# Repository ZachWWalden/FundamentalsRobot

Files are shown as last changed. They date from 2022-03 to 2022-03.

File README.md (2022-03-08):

# FundamentalsRobot
Reference Design Robot PCB for Oklahoma Christian University's Introductory E.C.E. Course, Fundamentals.
This design is meant to guide you in designing the schematic and possibly give some general layout tips.

# Things To Note
This design is not intended to be manufactured. This was achieved using surface mount resistors, capacitors, and screw terminals that the school does not have.
Over the few lessons we will do, we will build a board that uses components the school does have and, that if you so wish could be manufactured.

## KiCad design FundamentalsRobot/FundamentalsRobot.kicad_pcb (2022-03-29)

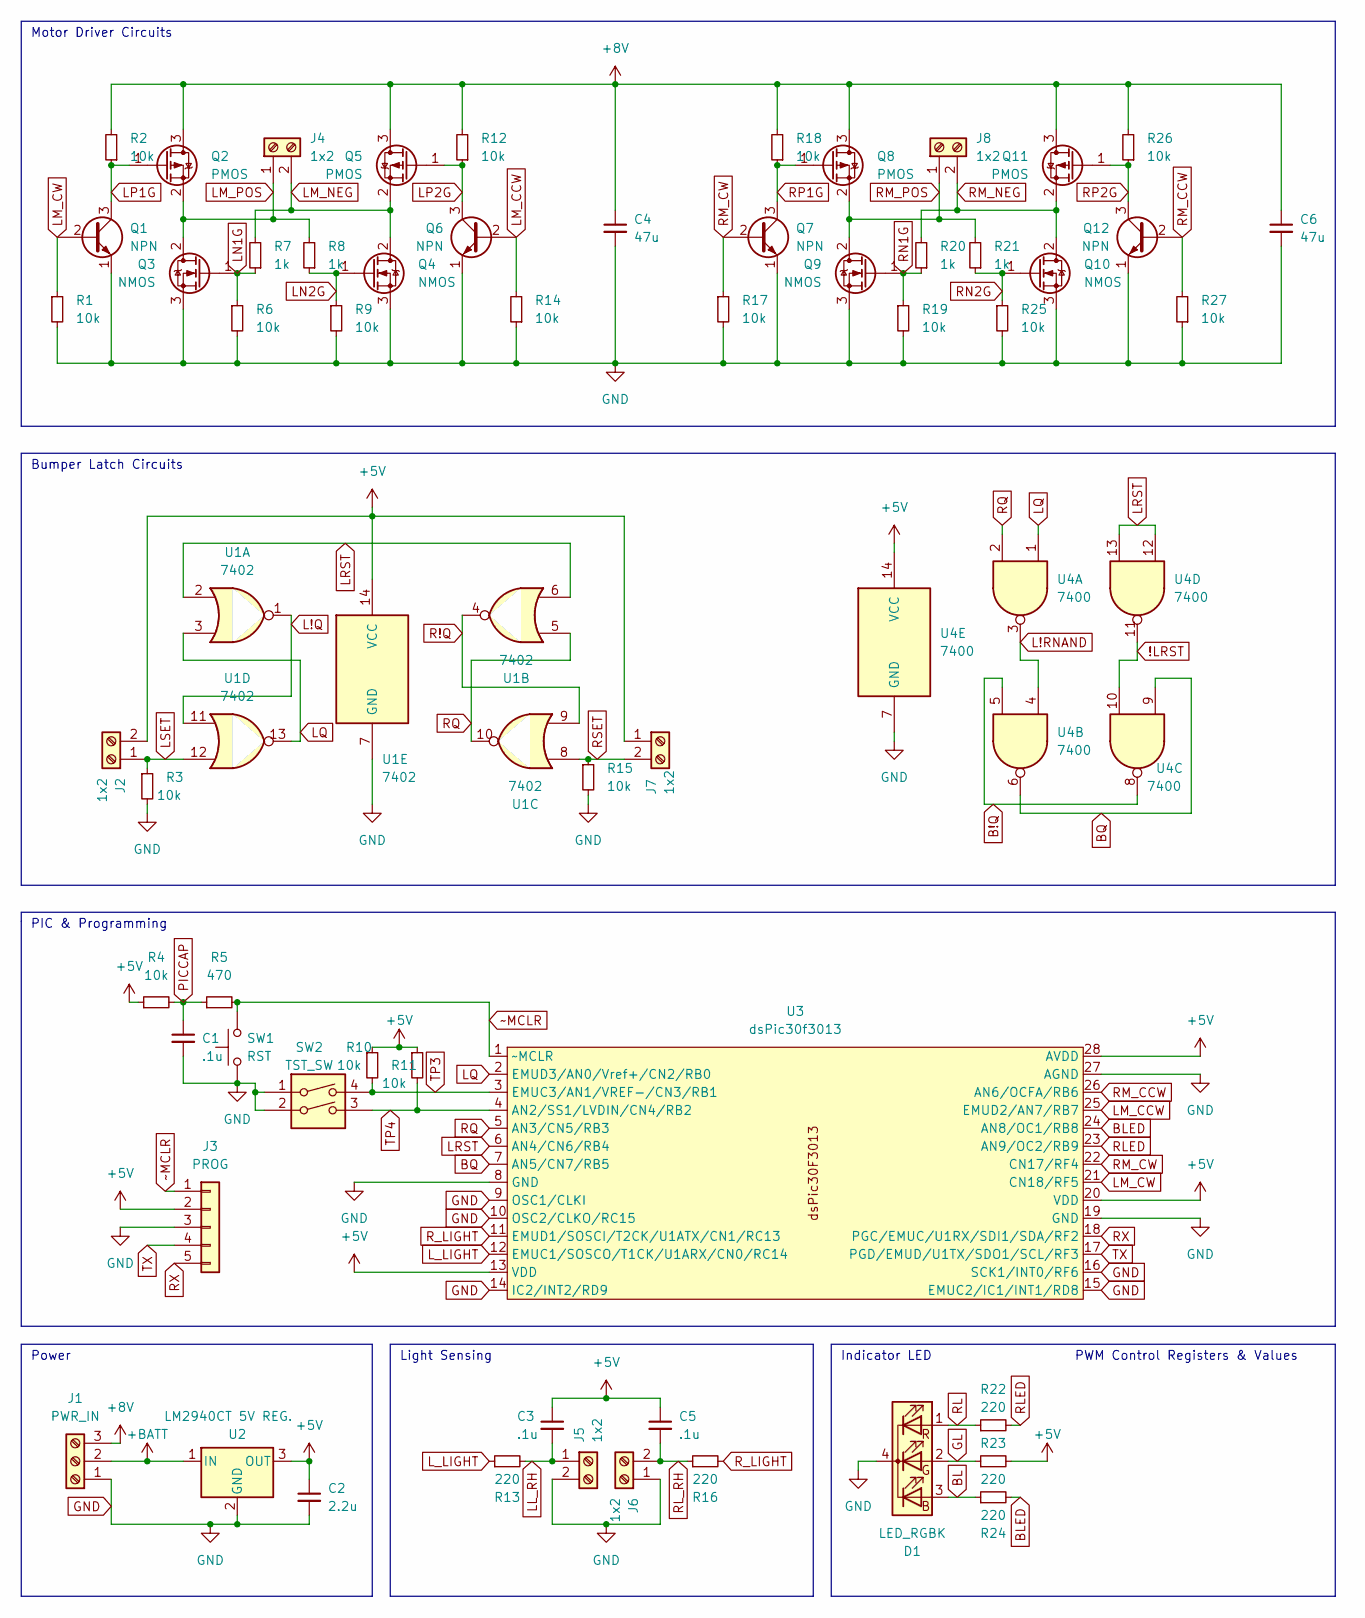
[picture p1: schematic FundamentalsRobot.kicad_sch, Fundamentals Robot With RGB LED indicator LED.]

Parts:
C1, C3, C5: .1u; C_0603_1608Metric
C2: 2.2u; C_0603_1608Metric
C4, C6: 47u; C_1206_3216Metric
D1: LED_RGBK; RKGB
J1: PWR_IN; TerminalBlock_Altech_AK300-3_P5.00mm
J2, J4, J5, J6, J7, J8: 1x2; TerminalBlock_Altech_AK300-2_P5.00mm
J3: PROG; PinHeader_1x05_P2.54mm_Vertical
Q1, Q6, Q7, Q12: NPN; TO-92
Q2, Q5, Q8, Q11: PMOS; TO-220-3_Vertical
Q3, Q4, Q9, Q10: NMOS; TO-220-3_Vertical
R1, R2, R3, R4, R6, R9, R10, R11, R12, R14, R15, R17, R18, R19, R25, R26, R27: 10k; R_0603_1608Metric
R5: 470; R_0603_1608Metric
R7, R8, R20, R21: 1k; R_0603_1608Metric
R13, R16, R22, R23, R24: 220; R_0603_1608Metric
SW1: RST; PinHeader_1x02_P2.54mm_Vertical
SW2: TST_SW; SW_DIP_SPSTx02_Piano_CTS_Series194-2MSTN_W7.62mm_P2.54mm
U1: 7402; DIP-14_W7.62mm
U2: LM2940CT 5V REG.; TO-220-3_Vertical
U3: dsPic30f3013; DIP-28_W7.62mm
U4: 7400; DIP-14_W7.62mm

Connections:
!LRST: U4.10, U4.11
+5V: C2.1, C3.1, C5.1, J2.2, J3.2, J7.1, R4.1, R10.1, R11.1, R23.2, U1.14 (VCC), U2.3 (OUT), U3.13 (VDD), U3.20 (VDD), U3.28 (AVDD), U4.14 (VCC)
+8V: C4.1, C6.1, J1.3, Q2.3 (D), Q5.3 (D), Q8.3 (D), Q11.3 (D), R2.2, R12.2, R18.2, R26.2
+BATT: J1.2, U2.1 (IN)
B!Q: U4.5, U4.8
BL: D1.3 (BA), R24.1
BLED: R24.2, U3.24 (AN8/OC1/RB8)
BQ: U3.7 (AN5/CN7/RB5), U4.6, U4.9
GL: D1.2 (GA), R23.1
GND: C1.2, C2.2, C4.2, C6.2, D1.4 (K), J1.1, J3.3, J5.2, J6.1, Q1.1 (E), Q3.3 (S), Q4.3 (S), Q6.1 (E), Q7.1 (E), Q9.3 (S), Q10.3 (S), Q12.1 (E), R1.2, R3.2, R6.2, R9.2, R14.1, R15.2, R17.2, R19.2, R25.2, R27.1, SW1.1, SW2.1, SW2.2, U1.7 (GND), U2.2 (GND), U3.8 (GND), U3.9 (OSC1/CLKI), U3.10 (OSC2/CLKO/RC15), U3.14 (IC2/INT2/RD9), U3.15 (EMUC2/IC1/INT1/RD8), U3.16 (SCK1/INT0/RF6), U3.19 (GND), U3.27 (AGND), U4.7 (GND)
L!Q: U1.1, U1.11
L!RNAND: U4.3, U4.4
LL_RH: C3.2, J5.1, R13.2
LM_CCW: Q6.2 (B), R14.2, U3.25 (EMUD2/AN7/RB7)
LM_CW: Q1.2 (B), R1.1, U3.21 (CN18/RF5)
LM_NEG: J4.2, Q4.2 (D), Q5.2 (S), R7.2
LM_POS: J4.1, Q2.2 (S), Q3.2 (D), R8.2
LN1G: Q3.1 (G), R6.1, R7.1
LN2G: Q4.1 (G), R8.1, R9.1
LP1G: Q1.3 (C), Q2.1 (G), R2.1
LP2G: Q5.1 (G), Q6.3 (C), R12.1
LQ: U1.3, U1.13, U3.2 (EMUD3/AN0/Vref+/CN2/RB0), U4.1
LRST: U1.2, U1.6, U3.6 (AN4/CN6/RB4), U4.12, U4.13
LSET: J2.1, R3.1, U1.12
L_LIGHT: R13.1, U3.12 (EMUC1/SOSCO/T1CK/U1ARX/CN0/RC14)
PICCAP: C1.1, R4.2, R5.1
R!Q: U1.4, U1.9
RL: D1.1 (RA), R22.1
RLED: R22.2, U3.23 (AN9/OC2/RB9)
RL_RH: C5.2, J6.2, R16.1
RM_CCW: Q12.2 (B), R27.2, U3.26 (AN6/OCFA/RB6)
RM_CW: Q7.2 (B), R17.1, U3.22 (CN17/RF4)
RM_NEG: J8.2, Q10.2 (D), Q11.2 (S), R20.2
RM_POS: J8.1, Q8.2 (S), Q9.2 (D), R21.2
RN1G: Q9.1 (G), R19.1, R20.1
RN2G: Q10.1 (G), R21.1, R25.1
RP1G: Q7.3 (C), Q8.1 (G), R18.1
RP2G: Q11.1 (G), Q12.3 (C), R26.1
RQ: U1.5, U1.10, U3.5 (AN3/CN5/RB3), U4.2
RSET: J7.2, R15.1, U1.8
RX: J3.5, U3.18 (PGC/EMUC/U1RX/SDI1/SDA/RF2)
R_LIGHT: R16.2, U3.11 (EMUD1/SOSCI/T2CK/U1ATX/CN1/RC13)
TP3: R10.2, SW2.4, U3.3 (EMUC3/AN1/VREF-/CN3/RB1)
TP4: R11.2, SW2.3, U3.4 (AN2/SS1/LVDIN/CN4/RB2)
TX: J3.4, U3.17 (PGD/EMUD/U1TX/SDO1/SCL/RF3)
~MCLR: J3.1, R5.2, SW1.2, U3.1 (~MCLR)

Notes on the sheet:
Indicator LED
Power
Motor Driver Circuits
Light Sensing
PIC & Programming
Bumper Latch Circuits
PWM Control Registers & Values

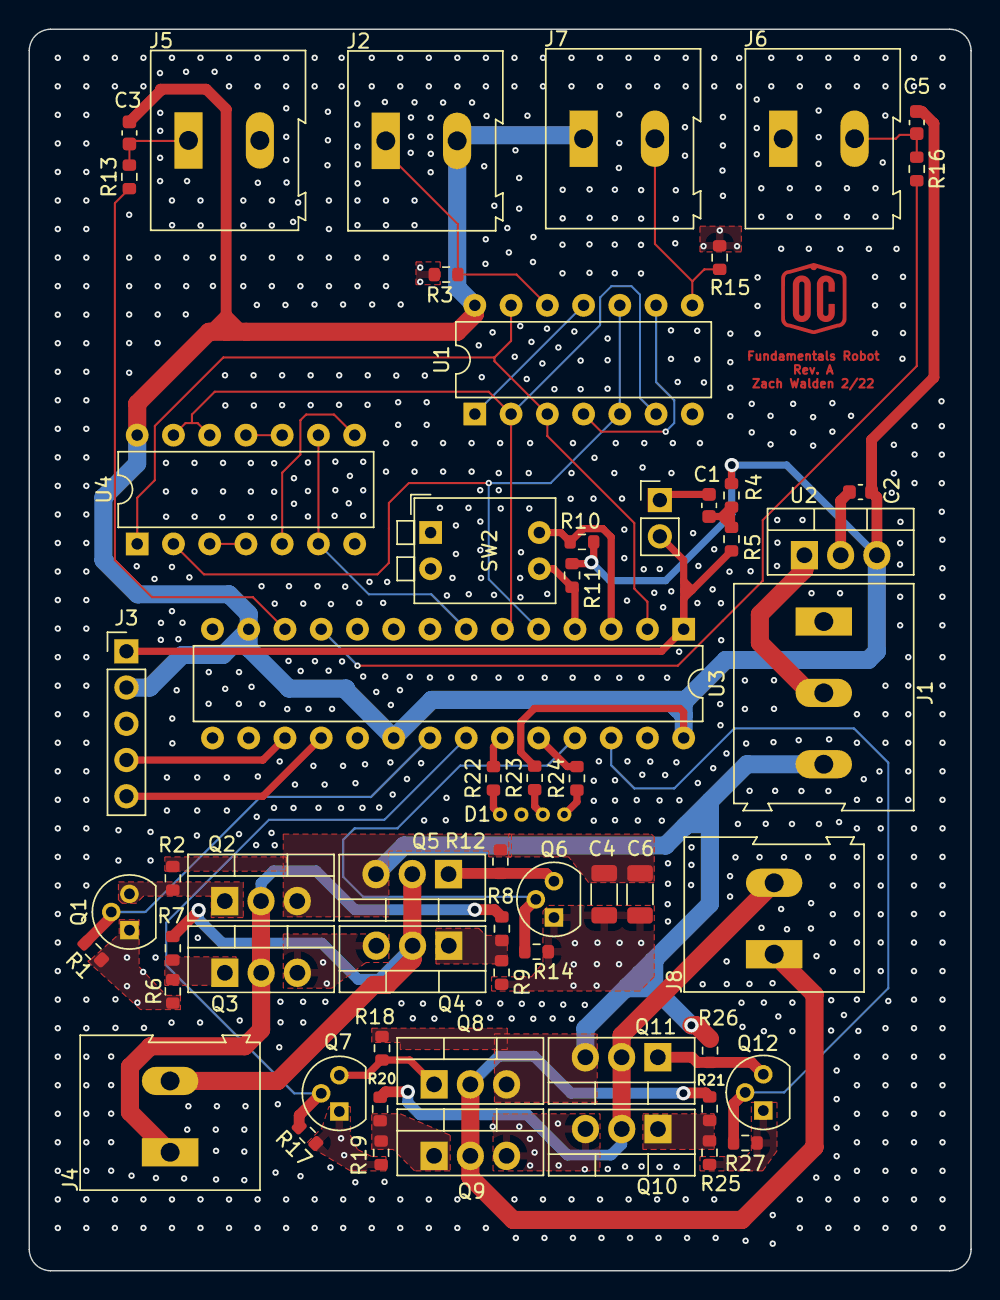
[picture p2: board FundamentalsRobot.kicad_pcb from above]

Board: 4 copper layers, 66.0 x 87.0 mm, 60 parts (0 on the bottom side), 46 nets.

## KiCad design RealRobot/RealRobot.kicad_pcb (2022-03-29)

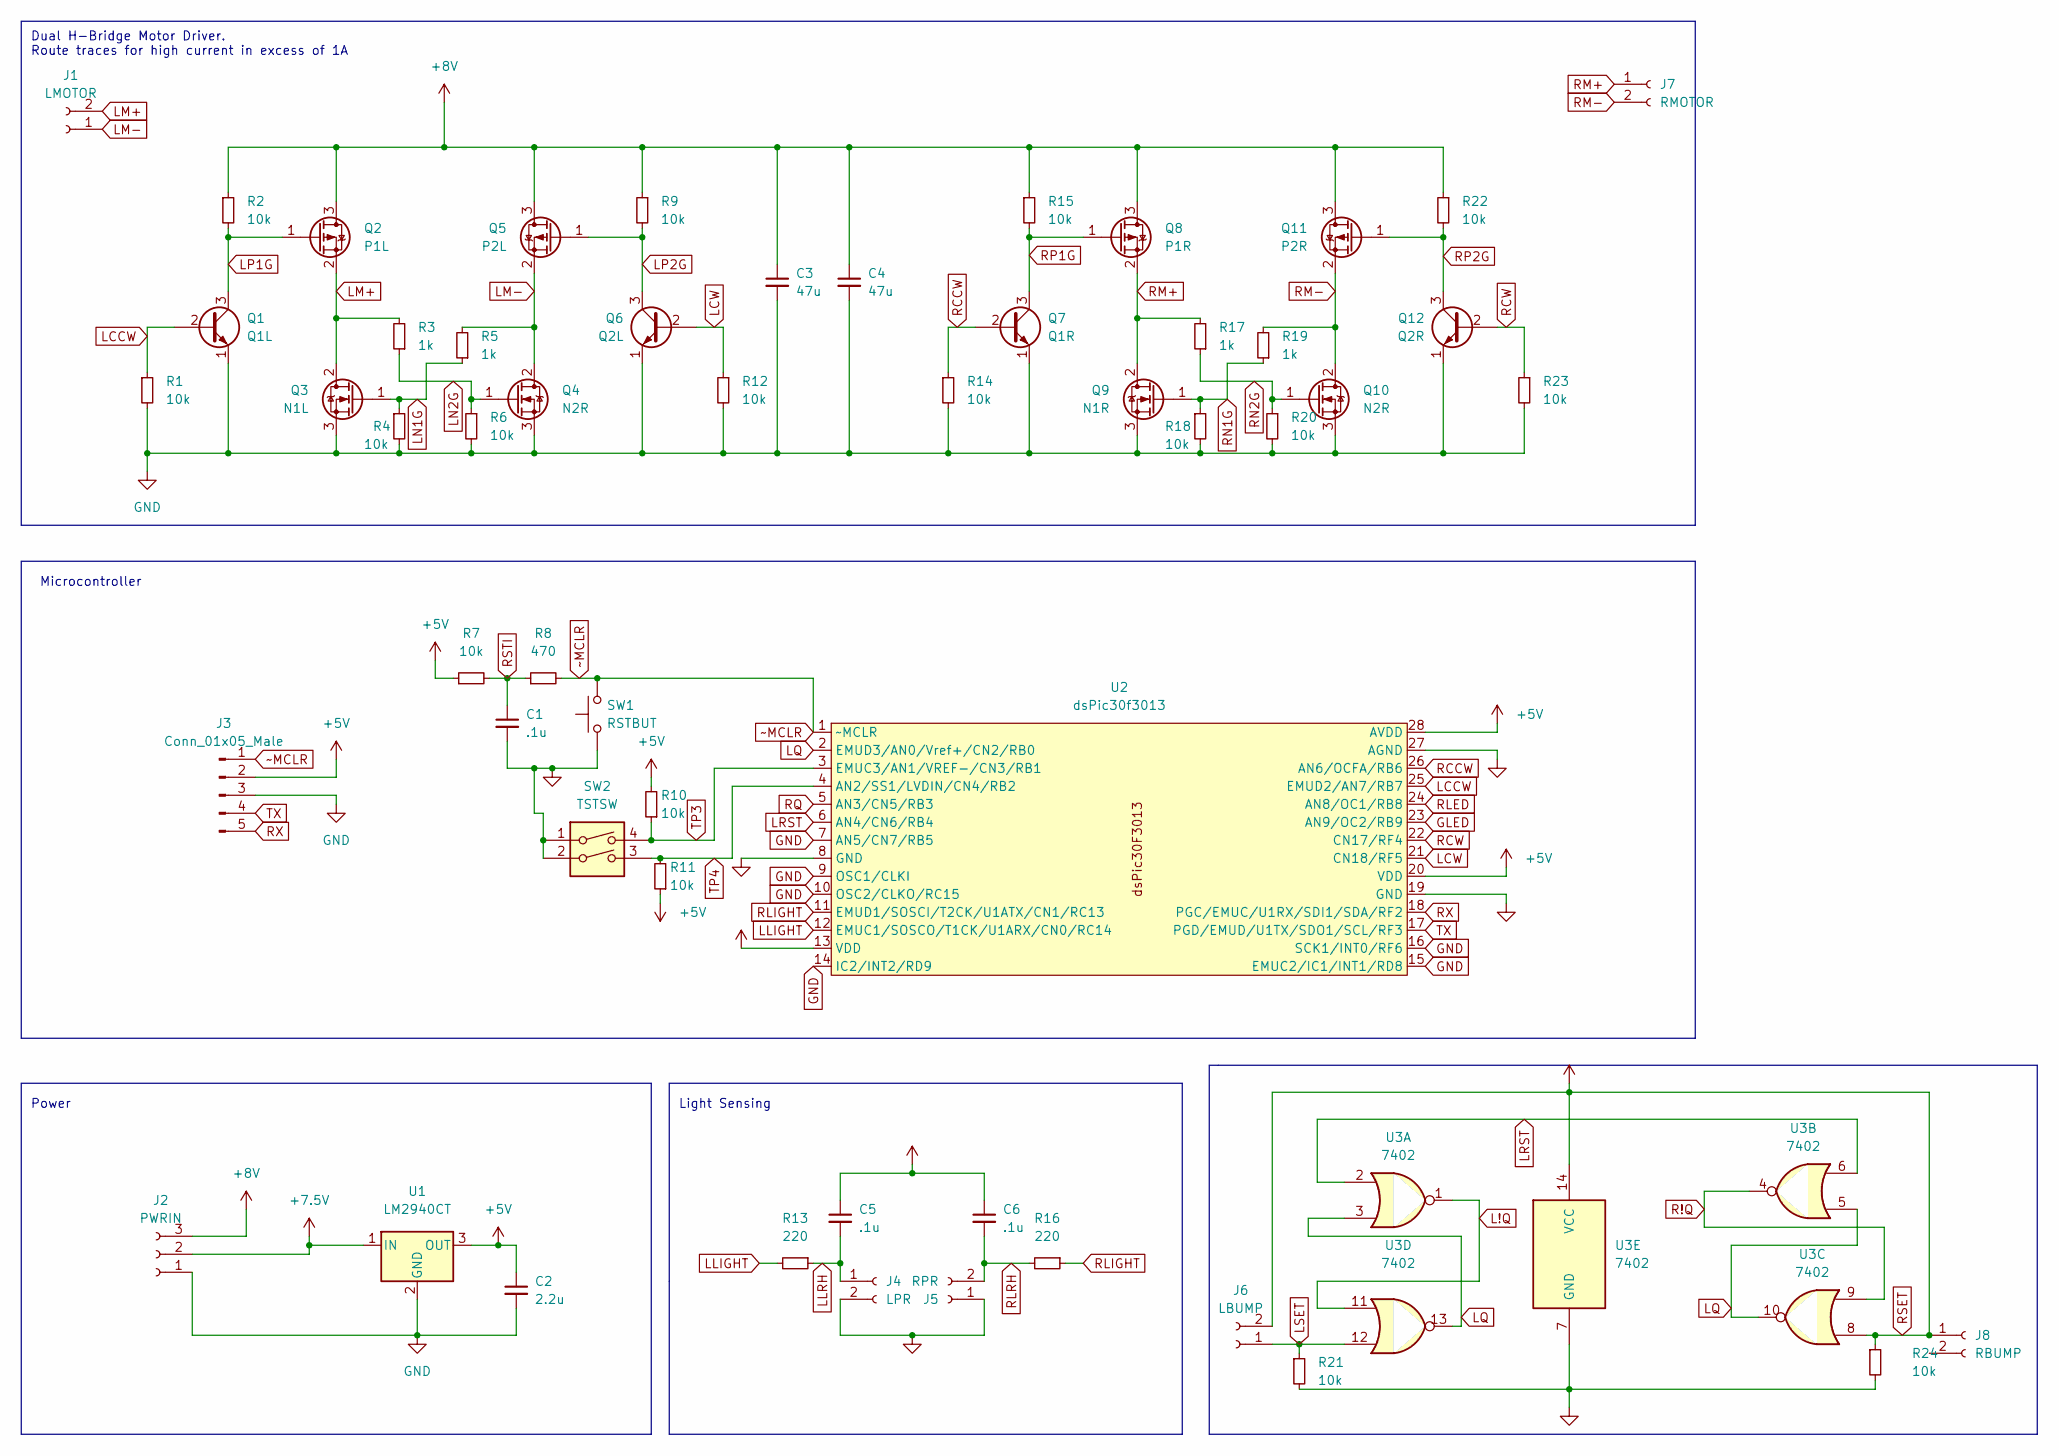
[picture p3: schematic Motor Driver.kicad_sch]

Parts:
C1, C5, C6: .1u; CP_Radial_D4.0mm_P1.50mm
C2: 2.2u; CP_Radial_D5.0mm_P2.00mm
C3, C4: 47u; CP_Radial_D5.0mm_P2.50mm
J1: LMOTOR
J2: PWRIN; PinHeader_1x03_P2.54mm_Vertical
J3: Conn_01x05_Male; PinHeader_1x05_P2.54mm_Vertical
J4: LPR; PinHeader_1x02_P2.54mm_Vertical
J5: RPR; PinHeader_1x02_P2.54mm_Vertical
J6: LBUMP; PinHeader_1x02_P2.54mm_Vertical
J7: RMOTOR; PinHeader_1x02_P2.54mm_Vertical
J8: RBUMP; PinHeader_1x02_P2.54mm_Vertical
Q1: Q1L; TO-92
Q2: P1L; TO-220-3_Vertical
Q3: N1L; TO-220-3_Vertical
Q4, Q10: N2R; TO-220-3_Vertical
Q5: P2L; TO-220-3_Vertical
Q6: Q2L; TO-92
Q7: Q1R; TO-92
Q8: P1R; TO-220-3_Vertical
Q9: N1R; TO-220-3_Vertical
Q11: P2R; TO-220-3_Vertical
Q12: Q2R; TO-92
R1, R2, R4, R6, R7, R9, R10, R11, R12, R14, R15, R18, R20, R21, R22, R23, R24: 10k; R_Axial_DIN0207_L6.3mm_D2.5mm_P10.16mm_Horizontal
R3, R5, R17, R19: 1k; R_Axial_DIN0207_L6.3mm_D2.5mm_P10.16mm_Horizontal
R8: 470; R_Axial_DIN0207_L6.3mm_D2.5mm_P10.16mm_Horizontal
R13, R16: 220; R_Axial_DIN0207_L6.3mm_D2.5mm_P10.16mm_Horizontal
SW1: RSTBUT; PinHeader_1x02_P2.54mm_Vertical
SW2: TSTSW; SW_DIP_SPSTx02_Piano_CTS_Series194-2MSTN_W7.62mm_P2.54mm
U1: LM2940CT; TO-220-3_Vertical
U2: dsPic30f3013; DIP-28_W7.62mm
U3: 7402; DIP-14_W7.62mm

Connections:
+7.5V: J2.2, U1.1 (IN)
+8V: C3.1, C4.1, J2.3, Q2.3 (D), Q5.3 (D), Q8.3 (D), Q11.3 (D), R2.1, R9.1, R15.1, R22.1
GLED: U2.23 (AN9/OC2/RB9)
L!Q: U3.1, U3.11
LCCW: Q1.2 (B), R1.1, U2.25 (EMUD2/AN7/RB7)
LCW: Q6.2 (B), R12.1, U2.21 (CN18/RF5)
LLIGHT: R13.2, U2.12 (EMUC1/SOSCO/T1CK/U1ARX/CN0/RC14)
LLRH: C5.2, J4.1, R13.1
LM+: J1.2, Q2.2 (S), Q3.2 (D), R3.2
LM-: J1.1, Q4.2 (D), Q5.2 (S), R5.2
LN1G: Q3.1 (G), R4.1, R5.1
LN2G: Q4.1 (G), R3.1, R6.1
LP1G: Q1.3 (C), Q2.1 (G), R2.2
LP2G: Q5.1 (G), Q6.3 (C), R9.2
LQ: U2.2 (EMUD3/AN0/Vref+/CN2/RB0), U3.3, U3.5, U3.10, U3.13
LRST: U2.6 (AN4/CN6/RB4), U3.2, U3.6
LSET: J6.1, R21.1, U3.12
R!Q: U3.4, U3.9
RCCW: Q7.2 (B), R14.1, U2.26 (AN6/OCFA/RB6)
RCW: Q12.2 (B), R23.1, U2.22 (CN17/RF4)
RLED: U2.24 (AN8/OC1/RB8)
RLIGHT: R16.1, U2.11 (EMUD1/SOSCI/T2CK/U1ATX/CN1/RC13)
RLRH: C6.2, J5.2, R16.2
RM+: J7.1, Q8.2 (S), Q9.2 (D), R17.2
RM-: J7.2, Q10.2 (D), Q11.2 (S), R19.2
RN1G: Q9.1 (G), R18.1, R19.1
RN2G: Q10.1 (G), R17.1, R20.1
RP1G: Q7.3 (C), Q8.1 (G), R15.2
RP2G: Q11.1 (G), Q12.3 (C), R22.2
RQ: U2.5 (AN3/CN5/RB3)
RSTI: C1.1, R7.2, R8.1
RX: J3.5, U2.18 (PGC/EMUC/U1RX/SDI1/SDA/RF2)
TP3: R10.1, SW2.4, U2.3 (EMUC3/AN1/VREF-/CN3/RB1)
TP4: R11.2, SW2.3, U2.4 (AN2/SS1/LVDIN/CN4/RB2)
TX: J3.4, U2.17 (PGD/EMUD/U1TX/SDO1/SCL/RF3)
~MCLR: J3.1, R8.2, SW1.2, U2.1 (~MCLR)

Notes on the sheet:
Microcontroller
Light Sensing
Dual H-Bridge Motor Driver. Route traces for high current in excess of 1A
Power

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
Board: 2 copper layers, 55 parts (0 on the bottom side), 35 nets, no tracks yet.

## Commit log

2022-03-08 Fixed Bumper Switch Pull Up Issue
    [FundamentalsRobot-B_Cu.gbr, FundamentalsRobot-B_Mask.gbr, FundamentalsRobot-B_Paste.gbr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]
2022-03-29 Added Schematic Done @ meeting along with a few clean ups.
    [FundamentalsRobot.kicad_pcb, FundamentalsRobot.kicad_sch, Motor Driver.kicad_sch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]
2022-04-28 Final Real Robot Controller Board
